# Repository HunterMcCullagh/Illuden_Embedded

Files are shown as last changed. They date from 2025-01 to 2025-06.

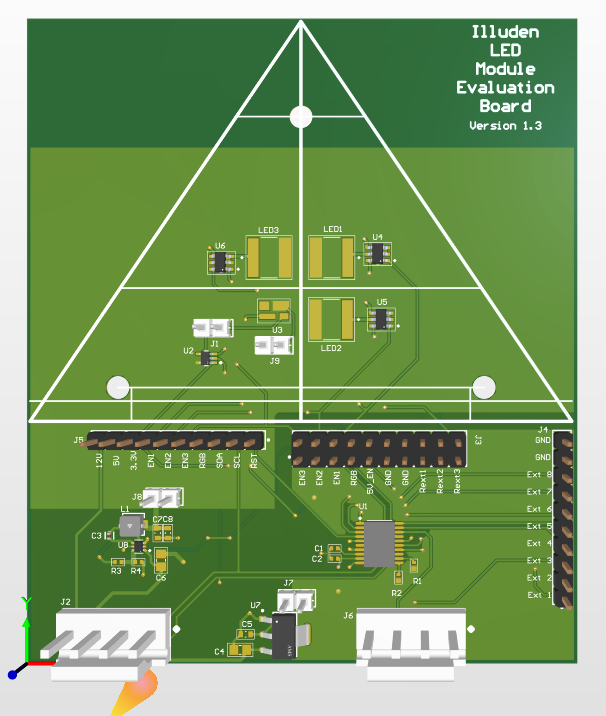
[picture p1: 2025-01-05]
LED_Module_Validation_Board/3D PCB.png

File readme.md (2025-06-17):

This repository contains the embedded portion of our Capstone Project, with the final goal to create a dynamic lighting solution.

In this repo there are two main features, the LED Modules & the ESP32 (in the Gatt Service Table Folder).

The LED Modules contain various light temperature LEDs, LED Drivers & an STM8S microcontroller that controls the LED drivers and acts as an I2C peripheral to receive data from the ESP32. There will be 50 modules attached at various angles on a mechanical frame to emit light in various directions. 

A screenshot of the inital prototype can be seen in the figure below, the end goal is to have all the components fit within the triangle shape.

2D PCB

This is what the final design looked like 

LED_board

The ESP32 in this project acts as a Bluetooth device for an iOS device to connect to with the app we are developing. Additionally, the ESP32 functions as an I2C controller that sends lighting commands to all the LED modules.

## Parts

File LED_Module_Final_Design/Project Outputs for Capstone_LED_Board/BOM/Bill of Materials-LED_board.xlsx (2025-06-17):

Comment | Designator | Footprint
1uF | C1 | 0402 PACKAGE
100nF | C2 | 0402 PACKAGE
100nF | C3 | FP-C0402-BB-MFG
10uF | C4, C7 | 0805 PACKAGE
15uF | C5, C6 | 0603 PACKAGE
22uF | C8 | 0603 PACKAGE
6500K LED | D1 | LED PACKAGE TOP
5000K LED | D2 | LED PACKAGE TOP
2700K LED | D3 | LED PACKAGE TOP
61300411121 | J1, J2 | 61300411121
2.2uH | L1 | FP-IHLP-1212BZ-11-MFG
1Ω | R1, R2, R3, R4, R5, R6, R7, R8, R9, R10, R11, R12 | RESC1609X50X30NL10T20
4.7kΩ | R13, R14 | 0402 PACKAGE
52.3kΩ | R15 | 0402 PACKAGE
10kΩ | R16 | 0402 PACKAGE
Test Point | RGB_SIG, TP2, TP3, TP4 | TEST POINT
Solder Bridge | SB1, SB2, SB3, SB4, SB5, SB6, SB7, SB8, SB9 | SOLDER BRIDGE
SN74LXC1T14DCKR | U1 | FP-DCK0005A-MFG
STM8S003F3P6 | U2 | STM-TSSOP20_V
Neopixel_3535 | U3 | NEOPIXEL
BCR421UW6-7 | U4, U5, U6 | SOT95P280X140-6N
AP62301 | U7 | AP62301
AMS1117-3.3 | U8 | FP-AMS1117-IPC_C

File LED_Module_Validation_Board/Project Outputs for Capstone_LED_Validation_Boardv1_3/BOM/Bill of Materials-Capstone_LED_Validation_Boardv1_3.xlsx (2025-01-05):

Comment | Designator | Footprint
1uF | C1 | 0402 PACKAGE
100nF | C2 | 0402 PACKAGE
100nF | C3 | FP-C0402-BB-MFG
10uF | C4, C6 | 0805 PACKAGE
22uF | C5 | 0603 PACKAGE
15uF | C7, C8 | 0603 PACKAGE
6500K LED | D1 | 2424 Package
5000K LED | D2 | 2424 Package
2700K LED | D3 | 2424 Package
TSW-102-26-F-S | J1, J7, J8, J9 | SMTC-TSW-102-26-XX-S
640445-4 | J2, J6 | TECO-640445-4_V
61302021121 | J3 | 61302021121
61301011121 | J4, J5 | 61301011121
2.2uH | L1 | FP-IHLP-1212BZ-11-MFG
4.7kΩ | R1, R2 | 0402 PACKAGE
52.3kΩ | R3 | 0402 PACKAGE
10kΩ | R4 | 0402 PACKAGE
STM8S003F3P6 | U1 | STM-TSSOP20_V
SN74LXC1T14DCKR | U2 | FP-DCK0005A-MFG
Neopixel_3535 | U3 | Neopixel
BCR421UW6-7 | U4, U5, U6 | SOT95P280X140-6N
AMS1117-3.3 | U7 | FP-AMS1117-IPC_C
AP62301 | U8 | AP62301

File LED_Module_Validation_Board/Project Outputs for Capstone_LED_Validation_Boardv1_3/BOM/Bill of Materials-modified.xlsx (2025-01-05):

Comment | Designator | Footprint
1uF | C1 | 0402 PACKAGE
100nF | C2 | 0402 PACKAGE
10uF | C3, C4, C6 | 0805 PACKAGE
22uF | C5 | 0603 PACKAGE
15uF | C7, C8 | 0603 PACKAGE
2.2uH | L1 | FP-IHLP-1212BZ-11-MFG
4.7kΩ | R1, R2 | 0402 PACKAGE
52.3kΩ | R3 | 0402 PACKAGE
10kΩ | R4 | 0402 PACKAGE
STM8S003F3P6 | U1 | STM-TSSOP20_V
SN74LXC1T14DCKR | U2 | FP-DCK0005A-MFG
BCR421UW6-7 | U4, U5, U6 | SOT95P280X140-6N
AMS1117-3.3 | U7 | FP-AMS1117-IPC_C
AP62301 | U8 | AP62301

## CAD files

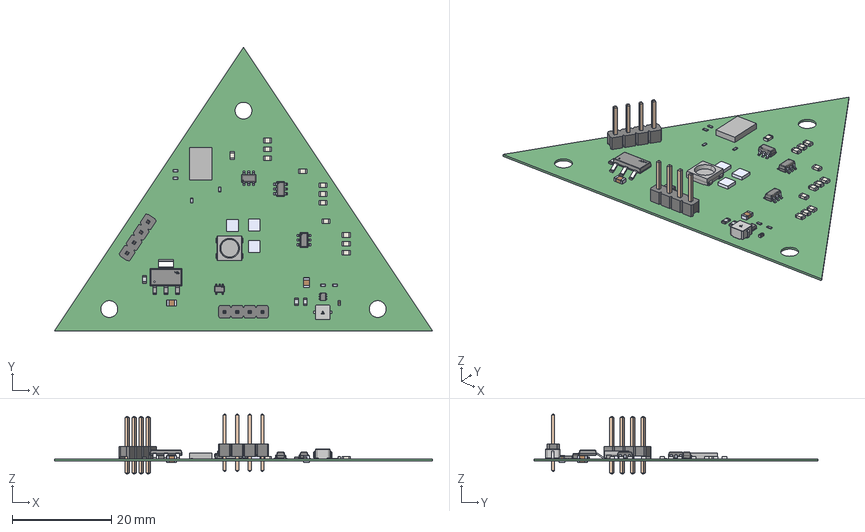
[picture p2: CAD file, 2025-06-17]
LED_Module_Final_Design/Project Outputs for Capstone_LED_Board/ExportSTEP/LED_board.step
76.2 x 57.1 x 12.0 mm
Notch_2
Extruded x 37
Package
Leads
Logo x 2
Pins
6130xx11121_PIN x 8
Body_1.6x0.8x0.8x0.35 x 3
Contact_0.8x0.8x0.35 x 6
GCM2165C1H152JA16D x 2
terminals
value
SK6812--3DModel-STEP-1_RGB8421504
LEDs_model x 3

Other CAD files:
I2C_peripheral_code/i2c_peripheral.stp
I2C_peripheral_code/STM8S_StdPeriph_Template/STVD/Cosmic/stm8af626x.stp
I2C_peripheral_code/STM8S_StdPeriph_Template/STVD/Raisonance/stm8s005.stp
I2C_peripheral_code/STM8S_StdPeriph_Template/STVD/Cosmic/stm8s903.stp
I2C_peripheral_code/STM8S_StdPeriph_Template/STVD/Raisonance/stm8s103.stp
I2C_peripheral_code/STM8S_StdPeriph_Template/STVD/Cosmic/stm8s103.stp
I2C_peripheral_code/STM8S_StdPeriph_Template/STVD/Raisonance/stm8s208.stp
I2C_peripheral_code/STM8S_StdPeriph_Template/STVD/Cosmic/stm8s207.stp
I2C_peripheral_code/STM8S_StdPeriph_Template/STVD/Raisonance/stm8s007.stp
I2C_peripheral_code/STM8S_StdPeriph_Template/STVD/Cosmic/stm8af52ax.stp
I2C_peripheral_code/STM8S_StdPeriph_Template/STVD/Raisonance/stm8s105.stp
I2C_peripheral_code/STM8S_StdPeriph_Template/STVD/Cosmic/stm8s105.stp
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

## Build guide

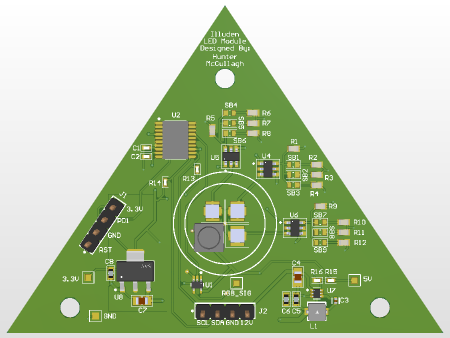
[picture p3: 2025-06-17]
LED_Module_Final_Design/Project Outputs for Capstone_LED_Board/PCB 3D Print/LED_board.png

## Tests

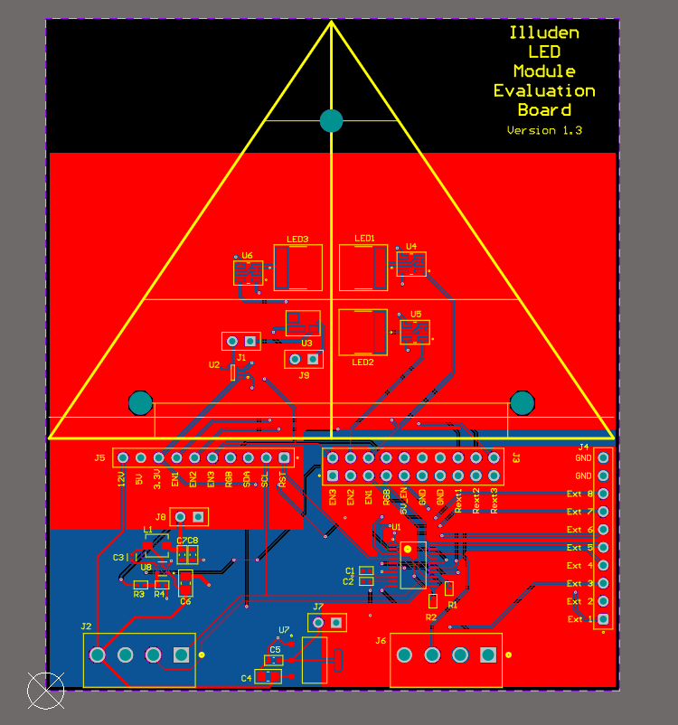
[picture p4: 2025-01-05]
LED_Module_Validation_Board/2D PCB.png

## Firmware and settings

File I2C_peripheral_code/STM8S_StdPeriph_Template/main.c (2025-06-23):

/**
  ******************************************************************************
	//Firmware for the LED Modules of the Illuden Project
  ******************************************************************************
  */

/* Includes ------------------------------------------------------------------*/
#include "stm8s.h"
#include "stm8s_eval.h"
#include "main.h"
#include <stdbool.h>


#define AFR ((volatile unsigned char*)0x50E0) //Alternate function register


uint8_t address_found = 0x00;

volatile uint8_t RGB_total_count = 0;//number of interrupts required to send a bit
volatile uint8_t RGB_high_count = 0;


//I2C related variables
volatile uint8_t I2C_data_received = 0;
extern uint8_t Slave_Buffer_Rx[];

uint8_t pwm_2700k = 0;
uint8_t pwm_5000k = 0;
uint8_t pwm_6500k = 0;
uint8_t RGB_red = 0;
uint8_t RGB_green = 0;
uint8_t RGB_blue = 0;



/* Private typedef -----------------------------------------------------------*/
/* Private define ------------------------------------------------------------*/
/* Private macro -------------------------------------------------------------*/
/* Private variables ---------------------------------------------------------*/
/* Private function prototypes -----------------------------------------------*/
/* Private functions ---------------------------------------------------------*/
/* Public functions ----------------------------------------------------------*/

void GPIO_Init_PD2(void) {
    // Set pin PD2 as input with pull-up and interrupt enabled
		GPIOD->DDR &= ~(1 << 2);  // Configure PD2 as input (DDR = 0)
		GPIOD->CR1 |= (1 << 2);   // Enable internal pull-up for PD2
    GPIOD->CR2 |= (1 << 2);   // Enable interrupt for PD2
}

void EXTI_Config(void) {
    EXTI_CR1 |= (0x02 << 4); // Set PORTD sensitivity to falling edge (bits 4-5 for PORTD)
}

void I2C_interrupt_init(void){
	I2C->ITR = I2C_ITR_ITBUFEN | I2C_ITR_ITEVTEN | I2C_ITR_ITERREN;
	
	GPIOB->DDR &= ~((1 << 4) | (1 << 5)); // PB4 (SDA) and PB5 (SCL) as input
	GPIOB->CR1 |= (1 << 4) | (1 << 5);   // Enable pull-up resistors
	GPIOB->CR2 |= (1 << 4) | (1 << 5);   // Enable fast mode

}

//Initialize I2C 
void initI2c(void) {
  // set I2C (IRQ19) software interrupt priority to 2 (next to lowest)
  ITC->ISPR5 = (ITC->ISPR5 & ~0xc0) | 0x00; // 0b00 => level 2
  I2C->CR1 &= ~I2C_CR1_PE;  // start with peripheral off (PE = 0)
 
  // I2C_CR1_NOSTRETCH  |   // 0x80  Clock Stretching Disable (Stretching enabled)
  // I2C_CR1_ENGC       |   // 0x40  General Call Enable (master only)
  // I2C_CR1_PE         |   // 0x01  Peripheral Enable (set at end)
  I2C->CR1 = 0;
 
  // I2C_CR2_SWRST  |   // 0x80  Software Reset
  // I2C_CR2_POS    |   // 0x08  Acknowledge (ACK is for current byte)
  // I2C_CR2_ACK    |   // 0x04  Acknowledge Enable (set at end)
  // I2C_CR2_STOP   |   // 0x02  Stop Generation  (1 => send stop  -- not used)
  // I2C_CR2_START  |   // 0x01  Start Generation (1 => send start -- not used)
  I2C->CR2 = 0;
 
  I2C->FREQR = 16; // I2C frequency register, 16MHz {>= 4MHz for 400k}
 
  // I2C_OARL_ADD, addr = 0x20
  // I2C_OARL_ADD0  Interface Address bit0 (not used in 7-bit addr)
  I2C->OARL = 0x29 << 1;  // I2C own address register LSB, this matches the address on my scope
 
  // I2C_OARH_ADDMODE  | // 0x80  Addressing Mode (7-bit addr)
  // I2C_OARH_ADD      | // 0x06  Interface Address bits [9..8] (for 10-bit addr)
  I2C->OARH = I2C_OARH_ADDCONF; // Address Mode Configuration (must be 1 for some odd reason)
 
  I2C->ITR =  // I2C interrupt register -- all type ints enabled
    I2C_ITR_ITBUFEN   |   // 0x04  Buffer Interrupt Enable
    I2C_ITR_ITEVTEN   |   // 0x02  Event Interrupt Enable
    I2C_ITR_ITERREN;      // 0x01  Error Interrupt Enable
 
  // I2C->CCRL       // I2C clock control register low  (master only)
  // I2C->CCRH       // I2C clock control register high (master only)
  // I2C->TRISER     // I2C maximum rise time register  (master only)
 
  I2C->CR1 |= I2C_CR1_PE;  // 0x01  Peripheral Enable (enable pins)
  I2C->CR2 |= I2C_CR2_ACK; //send ack every byte (why must this be last?) 
}


//Initialize Tim1
void tim1_init(void)
{
    // Step 1: Enable clock for TIM1
    CLK->PCKENR1 |= CLK_PCKENR1_TIM1; // Enable TIM1 clock in peripheral clock register

    // Step 2: De-initialize TIM1 (reset its settings)
    TIM1->CR1 = 0x00;   // Reset control register 1
    TIM1->CR2 = 0x00;   // Reset control register 2
    TIM1->SMCR = 0x00;  // Disable the slave mode control register
    TIM1->IER = 0x00;   // Disable all interrupts
    TIM1->SR1 = 0x00;   // Clear interrupt status flags
    TIM1->SR2 = 0x00;   // Clear additional status flags

    // Step 3: Set the prescaler value
    TIM1->PSCRH = 0x00; // High byte of prescaler = 0
    TIM1->PSCRL = 0x00; // Low byte of prescaler = 0 (Prescaler = 1)

    // Step 4: Set the auto-reload value (defines the timer period)
    TIM1->ARRH = 0x00;  // High byte of ARR (auto-reload)
    TIM1->ARRL = 0x01;  // Low byte of ARR (example: ARR = 0)

    // Step 5: Enable update interrupt if needed
    TIM1->IER |= TIM1_IER_UIE; // Enable update interrupt

    // Step 6: Enable TIM1 counter
    //TIM1->CR1 |= TIM1_CR1_CEN; // Set CEN bit to start the counter
}
void tim1_enable(void)
{
	//TIM1_Cmd(ENABLE);
	TIM1->CR1 |= TIM1_CR1_CEN;
}

void tim1_disable(void)
{
	//TIM1_Cmd(DISABLE);
	TIM1->CR1 &= ~TIM1_CR1_CEN;
	TIM1->SR1 &= ~TIM1_SR1_UIF; // Clear the update interrupt flag
}

//Assembly instructions to write a 1 to the RGB LED
//Required to use assembly as higher level commands were too slow
void WRITE_HIGH_BIT(void)
{
	//GPIOC->ODR |= (1 << 7);
	GPIOC->ODR &= ~(1 << 7);
	__asm("nop"); 
	__asm("nop");
	__asm("nop");
	__asm("nop");
	__asm("nop");
	__asm("nop"); 
	__asm("nop");
	__asm("nop");
	__asm("nop");
	__asm("nop");
	
	//GPIOC->ODR &= ~(1 << 7);
	GPIOC->ODR |= (1 << 7);
	__asm("nop");		
	__asm("nop");
	__asm("nop");
	__asm("nop");
	__asm("nop");
	__asm("nop");	
	__asm("nop");
	__asm("nop");	
	__asm("nop");
}

//Assembly instructions to write a 0 to the RGB LED
void WRITE_LOW_BIT(void)
{
	GPIOC->ODR &= ~(1 << 7);
	__asm("nop"); 
	__asm("nop");
	__asm("nop");
	__asm("nop");
	
	GPIOC->ODR |= (1 << 7);
	__asm("nop");		
}

//RGB LED requires a 24 bit 1 wire protocol message using a timing encoding
//The reason the code is wrote without loops is due to the limitations of the max STM8S frequency and available clock cycles
void send_RGB_message(uint8_t red, uint8_t blue, uint8_t green)
{
	//uint8_t i;
	__asm("SIM"); // Disable interrupts (for STM8)
	
	((red >> (7)) & 0x1) ? WRITE_HIGH_BIT() : WRITE_LOW_BIT();
	((red >> (6)) & 0x1) ? WRITE_HIGH_BIT() : WRITE_LOW_BIT();
	((red >> (5)) & 0x1) ? WRITE_HIGH_BIT() : WRITE_LOW_BIT();
	((red >> (4)) & 0x1) ? WRITE_HIGH_BIT() : WRITE_LOW_BIT();
	((red >> (3)) & 0x1) ? WRITE_HIGH_BIT() : WRITE_LOW_BIT();
	((red >> (2)) & 0x1) ? WRITE_HIGH_BIT() : WRITE_LOW_BIT();
	((red >> (1)) & 0x1) ? WRITE_HIGH_BIT() : WRITE_LOW_BIT();
	((red >> (0)) & 0x1) ? WRITE_HIGH_BIT() : WRITE_LOW_BIT();	
	
	((blue >> (7)) & 0x1) ? WRITE_HIGH_BIT() : WRITE_LOW_BIT();
	((blue >> (6)) & 0x1) ? WRITE_HIGH_BIT() : WRITE_LOW_BIT();
	((blue >> (5)) & 0x1) ? WRITE_HIGH_BIT() : WRITE_LOW_BIT();
	((blue >> (4)) & 0x1) ? WRITE_HIGH_BIT() : WRITE_LOW_BIT();
	((blue >> (3)) & 0x1) ? WRITE_HIGH_BIT() : WRITE_LOW_BIT();
	((blue >> (2)) & 0x1) ? WRITE_HIGH_BIT() : WRITE_LOW_BIT();
	((blue >> (1)) & 0x1) ? WRITE_HIGH_BIT() : WRITE_LOW_BIT();
	((blue >> (0)) & 0x1) ? WRITE_HIGH_BIT() : WRITE_LOW_BIT();	
	
	((green >> (7)) & 0x1) ? WRITE_HIGH_BIT() : WRITE_LOW_BIT();
	((green >> (6)) & 0x1) ? WRITE_HIGH_BIT() : WRITE_LOW_BIT();
	((green >> (5)) & 0x1) ? WRITE_HIGH_BIT() : WRITE_LOW_BIT();
	((green >> (4)) & 0x1) ? WRITE_HIGH_BIT() : WRITE_LOW_BIT();
	((green >> (3)) & 0x1) ? WRITE_HIGH_BIT() : WRITE_LOW_BIT();
	((green >> (2)) & 0x1) ? WRITE_HIGH_BIT() : WRITE_LOW_BIT();
	((green >> (1)) & 0x1) ? WRITE_HIGH_BIT() : WRITE_LOW_BIT();
	((green >> (0)) & 0x1) ? WRITE_HIGH_BIT() : WRITE_LOW_BIT();	
	
	__asm("RIM"); // Enable interrupts again
}



// Initialize PC7 as output
void PC7_Init(void) {
    // Set PC7 to output mode
    GPIOC->DDR |= (1 << 7); // Data Direction Register: 1 = Output
    GPIOC->CR1 |= (1 << 7); // Control Register 1: Push-pull mode
    GPIOC->CR2 |= (1 << 7); // Control Register 2: High speed
    //GPIOC->ODR &= ~(1 << 7); // Output Data Register: Initialize to LOW
		GPIOC->ODR |= (1 << 7); //init high bc converter
}

//Initialize PWM signals for the 3 LEDs
void TIM1_PWM_Init(void)
{
	
		SPI->CR1 = 0x00; // Disable SPI
		SPI->CR2 = 0x00;

		AFR[2] |= (1 << 6);  // Set PC6 alternate function (AFR for Port C)
		
		
		CLK->PCKENR1 |= (1 << CLK_PCKENR1_TIM1); 

    // Configure GPIO for TIM1_CH3 (PC3)
    GPIOC->DDR |= (1 << 3);  // Set PC3 as output
    GPIOC->CR1 |= (1 << 3);  // Push-pull mode
    GPIOC->CR2 |= (1 << 3);  // Fast mode

		//PC6 TIM1_CH1 (PC6)
		GPIOC->DDR |= (1 << 6);  // Set PC6 as output
		GPIOC->CR1 |= (1 << 6);  // Set PC6 to push-pull mode
		GPIOC->CR2 |= (1 << 6);  // Enable fast mode

    // Configure GPIO for TIM1_CH4 (PC4)
    GPIOC->DDR |= (1 << 4);  // Set PC4 as output
    GPIOC->CR1 |= (1 << 4);  // Push-pull mode
    GPIOC->CR2 |= (1 << 4);  // Fast mode

    // Reset TIM1 configuration
    TIM1->CR1 = 0x00;

    // Set TIM1 to up-counting mode
    TIM1->CR1 |= TIM1_CR1_CEN;  // Enable the counter

    // Set prescaler to divide the clock frequency
    TIM1->PSCRH = 0x00; // High byte of prescaler
    TIM1->PSCRL = 0x00; // Low byte of prescaler (prescaler = 1)

    // Set auto-reload value (frequency)
    TIM1->ARRH = 0x03;  // High byte (e.g., 0x03E8 for a 1 kHz PWM frequency)
    TIM1->ARRL = 0xE8;  // Low byte

    // Set duty cycle for Channel 3 (e.g., 50%)
    TIM1->CCR3H = 0x01; // High byte
    TIM1->CCR3L = 0xF4; // Low byte (e.g., 0x01F4 for 50% of 0x03E8)

		// Set duty cycle for Channel 1 (e.g., 50%)
		TIM1->CCR1H = 0x02; // High byte
		TIM1->CCR1L = 0xBC; // Low byte

    // Set duty cycle for Channel 4 (e.g., 75%)
    TIM1->CCR4H = 0x02; // High byte
    TIM1->CCR4L = 0xBC; // Low byte (e.g., 0x02BC for 75% of 0x03E8)

    // Configure PWM mode 1 on Channel 3
    TIM1->CCMR3 = TIM1_OCMODE_PWM1; // Set output compare mode to PWM1
    TIM1->CCER2 |= TIM1_CCER2_CC3E; // Enable the output on Channel 3

		// Configure PWM mode 1 on Channel 1
		TIM1->CCMR1 = TIM1_OCMODE_PWM1; // Set output compare mode to PWM1
		TIM1->CCER1 |= TIM1_CCER1_CC1E; // Enable the output on Channel 1

    // Configure PWM mode 1 on Channel 4
    TIM1->CCMR4 = TIM1_OCMODE_PWM1; // Set output compare mode to PWM1
    TIM1->CCER2 |= TIM1_CCER2_CC4E; // Enable the output on Channel 4

    // Enable TIM1
    TIM1->BKR |= TIM1_BKR_MOE; // Enable main output
    TIM1->CR1 |= TIM1_CR1_CEN; // Enable the timer counter

}

//set PWM of the GPIO connected to LED1
void set_LED1_PWM(uint8_t pwm)
{
	uint8_t factor;
	uint16_t newValue;
	
	newValue = pwm*10;
	
	TIM1->CCR3H = (newValue >>8) & 0xFF; // High byte
	TIM1->CCR3L = (newValue) & 0xFF; // Low byte (e.g., 0x01F4 for 50% of 0x03E8)
}

void set_LED2_PWM(uint8_t pwm)
{
	uint8_t factor;
	uint16_t newValue;
	
	newValue = pwm*10;
	
	TIM1->CCR4H = (newValue >>8) & 0xFF; // High byte
	TIM1->CCR4L = (newValue) & 0xFF; // Low byte (e.g., 0x01F4 for 50% of 0x03E8)
}

void set_LED3_PWM(uint8_t pwm)
{
	uint8_t factor;
	uint16_t newValue;
	
	newValue = pwm*10;
	
	TIM1->CCR1H = (newValue >>8) & 0xFF; // High byte
	TIM1->CCR1L = (newValue) & 0xFF; // Low byte (e.g., 0x01F4 for 50% of 0x03E8)
}

//A function required to ensure alternate function of GPIO function properly
void flash_fix(void) 
{
	
		const uint32_t AFR_DATA_ADDRESS = 0x4803;
    const uint32_t AFR_REQUIRED_VALUE = 0x1; // Enable TIM1_CH1 pin

    const uint16_t valueAndComplement = FLASH_ReadOptionByte(AFR_DATA_ADDRESS);
    const uint8_t currentValue = valueAndComplement >> 8;

    // Update value if the current option byte is corrupt or the wrong value
    if (valueAndComplement == 0 || currentValue != AFR_REQUIRED_VALUE) {
        FLASH_Unlock(FLASH_MEMTYPE_DATA);
        FLASH_ProgramOptionByte(AFR_DATA_ADDRESS, AFR_REQUIRED_VALUE);
        FLASH_Lock(FLASH_MEMTYPE_DATA);
    }
}


void parse_i2c_data(void) 
{
	if(pwm_2700k != Slave_Buffer_Rx[0])
	{
		pwm_2700k = Slave_Buffer_Rx[0];
		set_LED3_PWM(pwm_2700k);
	}
	
	if(pwm_5000k != Slave_Buffer_Rx[1])
	{
		pwm_5000k = Slave_Buffer_Rx[1];
		set_LED2_PWM(pwm_5000k);
	}
	
	if(pwm_6500k != Slave_Buffer_Rx[2])
	{
		pwm_6500k = Slave_Buffer_Rx[2];
		set_LED1_PWM(pwm_6500k);
	}

	if(RGB_red != Slave_Buffer_Rx[3] || RGB_green != Slave_Buffer_Rx[4] || RGB_blue != Slave_Buffer_Rx[5])
	{
		RGB_red 	= Slave_Buffer_Rx[3];
		RGB_green = Slave_Buffer_Rx[4];
		RGB_blue 	= Slave_Buffer_Rx[5];
		send_RGB_message(RGB_red,RGB_green,RGB_blue);
	}

}



/**
  * @brief  Main program.
  * @param  None
  * @retval None
  */
void main(void)
{
	uint8_t counter = 0;
	
	//uint8_t data[] = {0x01, 0x02, 0x03}; // Data to send
	//uint8_t slave_address = 0x50;        // Slave device address
	
	bool timer_started = false;
	
  /* system_clock / 1 */
  CLK_HSIPrescalerConfig(CLK_PRESCALER_HSIDIV1);
	
	// Optional: Verify that HSI is ready and stable
	while ((CLK->ICKR & CLK_ICKR_HSIRDY) == 0);

	// Ensure HSI is the active clock source (if not already)
  CLK_ClockSwitchConfig(CLK_SWITCHMODE_AUTO, CLK_SOURCE_HSI, DISABLE, CLK_CURRENTCLOCKSTATE_ENABLE);
  
	//GPIO Interrupt
	GPIO_Init_PD2();
	EXTI_Config();
	
	initI2c();
	
	PC7_Init();
	

  /* Enable general interrupts */
  enableInterrupts();

	//flash_fix(); //required for first time programming a STM8S device
	TIM1_PWM_Init();
	
	set_LED1_PWM(2); //6500
	set_LED2_PWM(2); //5000
	set_LED3_PWM(2); //2700
	


  /*Main Loop */
  while (1)
  {
		
		if(I2C_data_received)
		{
			parse_i2c_data();
			I2C_data_received = 0;
		}

  }
}

#ifdef  USE_FULL_ASSERT
/**
  * @brief  Reports the name of the source file and the source line number
  *   where the assert_param error has occurred.
  * @param  file: pointer to the source file name
  * @param  line: assert_param error line source number
  * @retval None
  */
void assert_failed(uint8_t* file, uint32_t line)
{
  /* User can add his own implementation to report the file name and line number,
     ex: printf("Wrong parameters value: file %s on line %d\r\n", file, line) */

  /* Infinite loop */
  while (1)
  {}
}
#endif

/**
  * @}
  */

/**
  * @}
  */

/************************ (C) COPYRIGHT STMicroelectronics *****END OF FILE****/

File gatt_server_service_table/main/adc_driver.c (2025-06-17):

/*
 * SPDX-FileCopyrightText: 2022-2023 Espressif Systems (Shanghai) CO LTD
 *
 * SPDX-License-Identifier: Apache-2.0
 */
#include <stdio.h>
#include <stdlib.h>
#include <string.h>
#include "freertos/FreeRTOS.h"
#include "freertos/task.h"
#include "soc/soc_caps.h"
#include "esp_log.h"
#include "esp_adc/adc_oneshot.h"
#include "esp_adc/adc_cali.h"
#include "esp_adc/adc_cali_scheme.h"

const static char *TAG = "EXAMPLE";

/*---------------------------------------------------------------
        ADC General Macros
---------------------------------------------------------------*/
//ADC1 Channels
#if CONFIG_IDF_TARGET_ESP32
#define EXAMPLE_ADC1_CHAN0          ADC_CHANNEL_4
#define EXAMPLE_ADC1_CHAN1          ADC_CHANNEL_5
#else
#define EXAMPLE_ADC1_CHAN0          ADC_CHANNEL_2
#define EXAMPLE_ADC1_CHAN1          ADC_CHANNEL_3
#endif

#if (SOC_ADC_PERIPH_NUM >= 2) && !CONFIG_IDF_TARGET_ESP32C3
/**
 * On ESP32C3, ADC2 is no longer supported, due to its HW limitation.
 * Search for errata on espressif website for more details.
 */
#define EXAMPLE_USE_ADC2            1
#endif

#if EXAMPLE_USE_ADC2
//ADC2 Channels
#if CONFIG_IDF_TARGET_ESP32
#define EXAMPLE_ADC2_CHAN0          ADC_CHANNEL_0
#else
#define EXAMPLE_ADC2_CHAN0          ADC_CHANNEL_0
#endif
#endif  //#if EXAMPLE_USE_ADC2

#define EXAMPLE_ADC_ATTEN           ADC_ATTEN_DB_12

static int adc_raw[2][10];
static int voltage[2][10];
static bool example_adc_calibration_init(adc_unit_t unit, adc_channel_t channel, adc_atten_t atten, adc_cali_handle_t *out_handle);
static void example_adc_calibration_deinit(adc_cali_handle_t handle);

bool adc_is_initialized = false;
adc_oneshot_unit_handle_t adc1_handle;
adc_oneshot_unit_init_cfg_t init_config1 = {
    .unit_id = ADC_UNIT_1,
};

void adc_init()
{
    //-------------ADC1 Init---------------//

    ESP_ERROR_CHECK(adc_oneshot_new_unit(&init_config1, &adc1_handle));
    //-------------ADC1 Config---------------//
    adc_oneshot_chan_cfg_t config = {
        .atten = EXAMPLE_ADC_ATTEN,
        .bitwidth = ADC_BITWIDTH_DEFAULT,
    };
    ESP_ERROR_CHECK(adc_oneshot_config_channel(adc1_handle, EXAMPLE_ADC1_CHAN0, &config));
    ESP_ERROR_CHECK(adc_oneshot_config_channel(adc1_handle, EXAMPLE_ADC1_CHAN1, &config));

    //-------------ADC1 Calibration Init---------------//
    adc_cali_handle_t adc1_cali_chan0_handle = NULL;
    adc_cali_handle_t adc1_cali_chan1_handle = NULL;
    adc_is_initialized = true;
}
void adc_deinit()
{
    //Tear Down
    ESP_ERROR_CHECK(adc_oneshot_del_unit(adc1_handle));
    adc_is_initialized = false;
}

int adc_read()
{
    if(adc_is_initialized == false)
    {
        adc_init();
    }

    ESP_ERROR_CHECK(adc_oneshot_read(adc1_handle, EXAMPLE_ADC1_CHAN0, &adc_raw[0][0])); //HM this is most of it
    ESP_LOGI(TAG, "ADC%d Channel[%d] Raw Data: %d", ADC_UNIT_1 + 1, EXAMPLE_ADC1_CHAN0, adc_raw[0][0]);
    vTaskDelay(pdMS_TO_TICKS(1000));

    ESP_ERROR_CHECK(adc_oneshot_read(adc1_handle, EXAMPLE_ADC1_CHAN1, &adc_raw[0][1]));
    ESP_LOGI(TAG, "ADC%d Channel[%d] Raw Data: %d", ADC_UNIT_1 + 1, EXAMPLE_ADC1_CHAN1, adc_raw[0][1]);
    vTaskDelay(pdMS_TO_TICKS(1000));

    return adc_raw[0][0];
}

/*---------------------------------------------------------------
        ADC Calibration
---------------------------------------------------------------*/
static bool example_adc_calibration_init(adc_unit_t unit, adc_channel_t channel, adc_atten_t atten, adc_cali_handle_t *out_handle)
{
    adc_cali_handle_t handle = NULL;
    esp_err_t ret = ESP_FAIL;
    bool calibrated = false;

#if ADC_CALI_SCHEME_CURVE_FITTING_SUPPORTED
    if (!calibrated) {
        ESP_LOGI(TAG, "calibration scheme version is %s", "Curve Fitting");
        adc_cali_curve_fitting_config_t cali_config = {
            .unit_id = unit,
            .chan = channel,
            .atten = atten,
            .bitwidth = ADC_BITWIDTH_DEFAULT,
        };
        ret = adc_cali_create_scheme_curve_fitting(&cali_config, &handle);
        if (ret == ESP_OK) {
            calibrated = true;
        }
    }
#endif

#if ADC_CALI_SCHEME_LINE_FITTING_SUPPORTED
    if (!calibrated) {
        ESP_LOGI(TAG, "calibration scheme version is %s", "Line Fitting");
        adc_cali_line_fitting_config_t cali_config = {
            .unit_id = unit,
            .atten = atten,
            .bitwidth = ADC_BITWIDTH_DEFAULT,
        };
        ret = adc_cali_create_scheme_line_fitting(&cali_config, &handle);
        if (ret == ESP_OK) {
            calibrated = true;
        }
    }
#endif

    *out_handle = handle;
    if (ret == ESP_OK) {
        ESP_LOGI(TAG, "Calibration Success");
    } else if (ret == ESP_ERR_NOT_SUPPORTED || !calibrated) {
        ESP_LOGW(TAG, "eFuse not burnt, skip software calibration");
    } else {
        ESP_LOGE(TAG, "Invalid arg or no memory");
    }

    return calibrated;
}

static void example_adc_calibration_deinit(adc_cali_handle_t handle)
{
#if ADC_CALI_SCHEME_CURVE_FITTING_SUPPORTED
    ESP_LOGI(TAG, "deregister %s calibration scheme", "Curve Fitting");
    ESP_ERROR_CHECK(adc_cali_delete_scheme_curve_fitting(handle));

#elif ADC_CALI_SCHEME_LINE_FITTING_SUPPORTED
    ESP_LOGI(TAG, "deregister %s calibration scheme", "Line Fitting");
    ESP_ERROR_CHECK(adc_cali_delete_scheme_line_fitting(handle));
#endif
}

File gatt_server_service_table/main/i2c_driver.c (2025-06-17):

#include <stdio.h>
#include <driver/i2c.h>
#include <string.h>
#include "i2c_driver.h"


#include "freertos/FreeRTOS.h"
#include "freertos/task.h"

#define I2C_MASTER_NUM I2C_NUM_0        // I2C port number
#define I2C_MASTER_SCL_IO 9           // GPIO for SCL was 19
#define I2C_MASTER_SDA_IO 8           // GPIO for SDA was 18
#define I2C_MASTER_FREQ_HZ 100000      // Frequency in Hz (100 kHz standard)
#define I2C_MASTER_TX_BUF_DISABLE 0    // Disable transmit buffer
#define I2C_MASTER_RX_BUF_DISABLE 0    // Disable receive buffer

#include "driver/gpio.h"

void configure_i2c_drive_strength() {
    gpio_set_drive_capability(I2C_MASTER_SDA_IO, GPIO_DRIVE_CAP_3); // Maximum drive strength
    gpio_set_drive_capability(I2C_MASTER_SCL_IO, GPIO_DRIVE_CAP_3); // Maximum drive strength
}


// Function to initialize the I2C driver
void i2c_master_init() {
    i2c_config_t i2c_conf = {
        .mode = I2C_MODE_MASTER,
        .sda_io_num = I2C_MASTER_SDA_IO,
        .sda_pullup_en = GPIO_PULLUP_ENABLE,
        .scl_io_num = I2C_MASTER_SCL_IO,
        .scl_pullup_en = GPIO_PULLUP_ENABLE,
        .master.clk_speed = I2C_MASTER_FREQ_HZ,
    };
    ESP_ERROR_CHECK(i2c_param_config(I2C_MASTER_NUM, &i2c_conf));
    ESP_ERROR_CHECK(i2c_driver_install(I2C_MASTER_NUM, i2c_conf.mode,
                                       I2C_MASTER_RX_BUF_DISABLE,
                                       I2C_MASTER_TX_BUF_DISABLE, 0));
}

// Function to scan for I2C peripherals
void i2c_scan() {
    printf("Scanning for I2C devices...\n");
    for (uint8_t addr = 1; addr < 127; addr++) {
        i2c_cmd_handle_t cmd = i2c_cmd_link_create();
        i2c_master_start(cmd);
        i2c_master_write_byte(cmd, (addr << 1) | I2C_MASTER_WRITE, true);
        i2c_master_stop(cmd);

        esp_err_t ret = i2c_master_cmd_begin(I2C_MASTER_NUM, cmd, pdMS_TO_TICKS(500));
        i2c_cmd_link_delete(cmd);

        if (ret == ESP_OK) {
            printf("Device found at address 0x%02X\n", addr);
        }
    }
    printf("I2C scan completed.\n");
}

esp_err_t LEDWriteRegs(uint8_t addr, uint8_t *data, size_t len)
{
    uint8_t writeBuf[len];  // First byte is the starting register
    memcpy(&writeBuf[0], data, len);

    return i2c_master_write_to_device(I2C_MASTER_NUM, addr, writeBuf, len, 1000);
}

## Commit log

2024-10-07 Initial BLE peripheral device commit
2025-01-05 Added LED Moduloe Evaluation Board Design
    [Bill of Materials-Capstone_LED_Validation_Boardv1_3.xlsx, Bill of Materials-modified.xlsx, Capstone_LED_Validation_Boardv1_3.PrjPcb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]
2025-01-05 Update readme.md with ESP32 info
2025-02-08 basic i2c commands integrated with Bluetooth
2025-03-03 basic ADC complete
2025-06-17 Added final LED Module Design
    [Bill of Materials-LED_board.xlsx, Capstone_LED_Board.PrjPcb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]
2025-06-17 ESP32 firmware documentation updates
2025-06-23 LED Module STM8 Firmware upload
    [i2c_peripheral.stp, stm8af52ax.stp, stm8af622x.stp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]
